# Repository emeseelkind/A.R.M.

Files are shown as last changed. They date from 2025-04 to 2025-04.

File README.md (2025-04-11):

# A.R.M. - Above-Elbow 3D-Printed Low-Cost Prosthetic

**Customizable Above-Elbow 3D-Printed Low-Cost Prosthetics**

By Queen's Biomedical Innovation Team (QBiT), the Perk Lab and Med-i Lab from Queen's University.

In collaboration with Burma Children Medical Fund (BCMF), a nonprofit based in Mae Sot, Tak, Thailand. BCMF focuses on funding medical treatment and support services, including accessible prosthetics for refugees and underserved Burmese communities along the Thai-Myanmar border. 

Our partnership focuses on designing and developing low-cost, 3D-printed, body-powered prosthetics. The labs provide both remote and on-site technical support and have sent three students to work in Mae Sot with BCMF so far.

This repository contains the CAD models and harness manual for our fully body-powered above-elbow prosthetic. The device is to be fabricated using locally available materials and support the everyday functional needs of patients.

# Features

• Fully body-powered design

• Made with materials accessible in-clinic

• Capable of assisting with common daily tasks

• Lightweight and easy to reproduce

• Total estimated material cost: $8.23–13.23 USD per device

• Open-source and adaptable for future development

# Files Included

• 5 CAD files for prosthetic components

• Harness system instructions and design notes

• Cost breakdown and materials list

• Preliminary testing results and feedback highlights

# In Progress

• Video demonstration of device assembly and usage will be added soon

• Ongoing testing with patients at BCMF in Thailand (April–August 2025)

• Planned integration into clinic workflow and future iterations for improved elbow movement and durability

• Movement of 5 fingers and interchangable end effectors will be added in the 2025-2026 school term

# Contact & Links

For inquiries or contributions:

• Email: qbit@engsoc.queensu.ca

• Website: [qbitqueensu.com](https://qbitqueensu.com)
           [labs.cs.queensu.ca/perklab/](https://labs.cs.queensu.ca/perklab/)
           [labs.cs.queensu.ca/medilab/](https://labs.cs.queensu.ca/medilab/)

**To volunteer, donate, or learn more please visit: [burmachildren.com/](https://burmachildren.com/)**

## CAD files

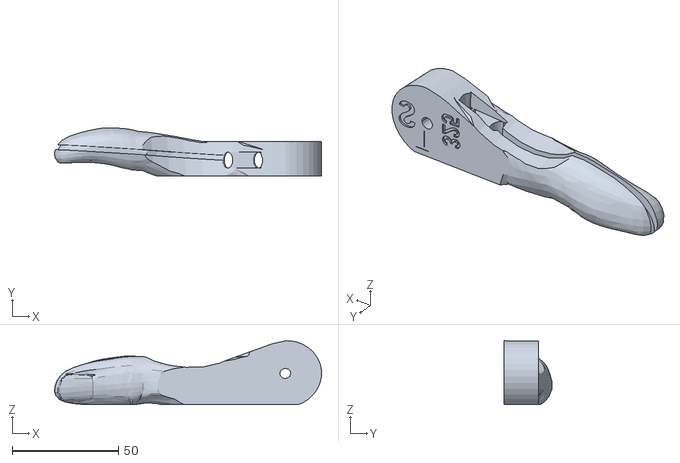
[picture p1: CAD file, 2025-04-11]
BCMFThumb.stl
125.7 x 22.8 x 30.2

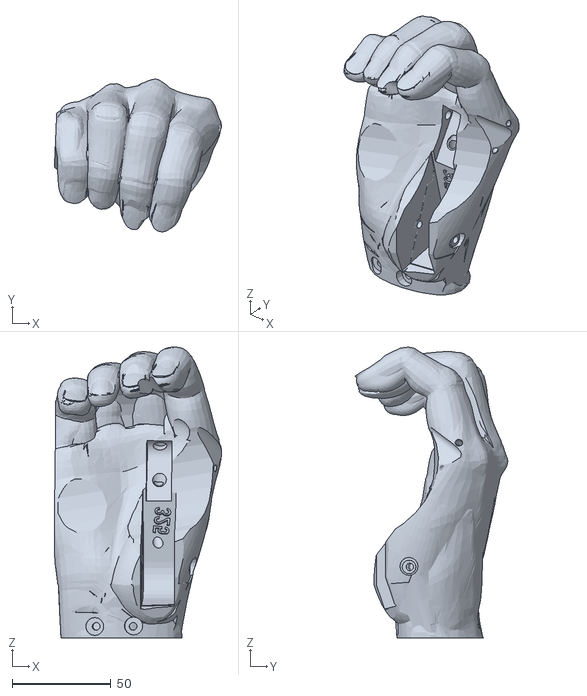
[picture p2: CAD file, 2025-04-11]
BCMFGripperHand.stl
84.9 x 77.6 x 147.7

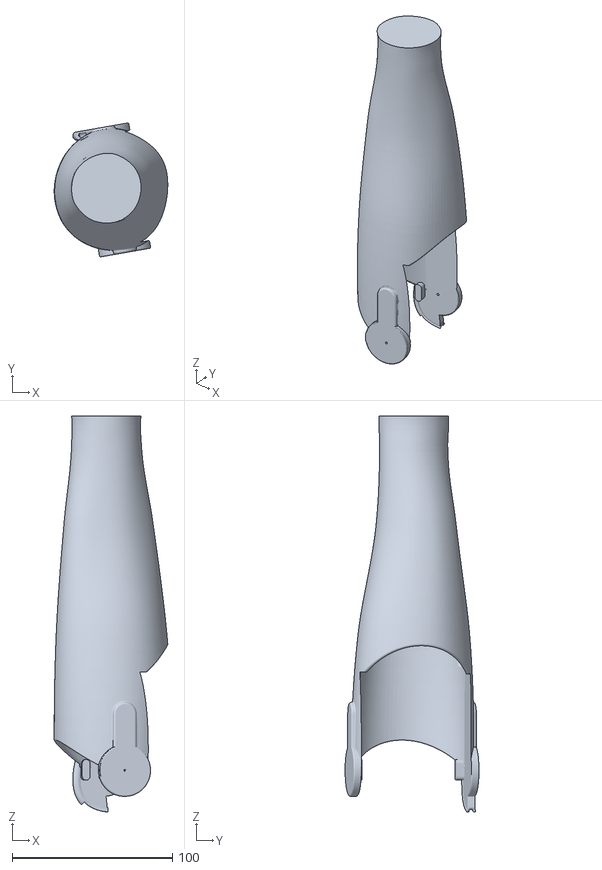
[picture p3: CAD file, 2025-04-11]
BCMFForearm.stl
70.8 x 83.6 x 246.9

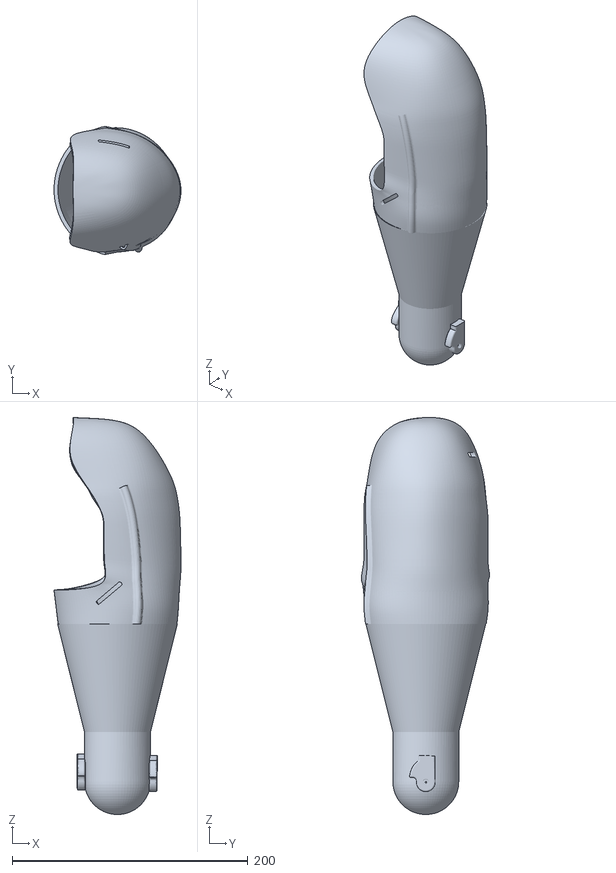
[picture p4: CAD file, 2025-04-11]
BCMFShoulder.stl
107.8 x 108.7 x 337.1

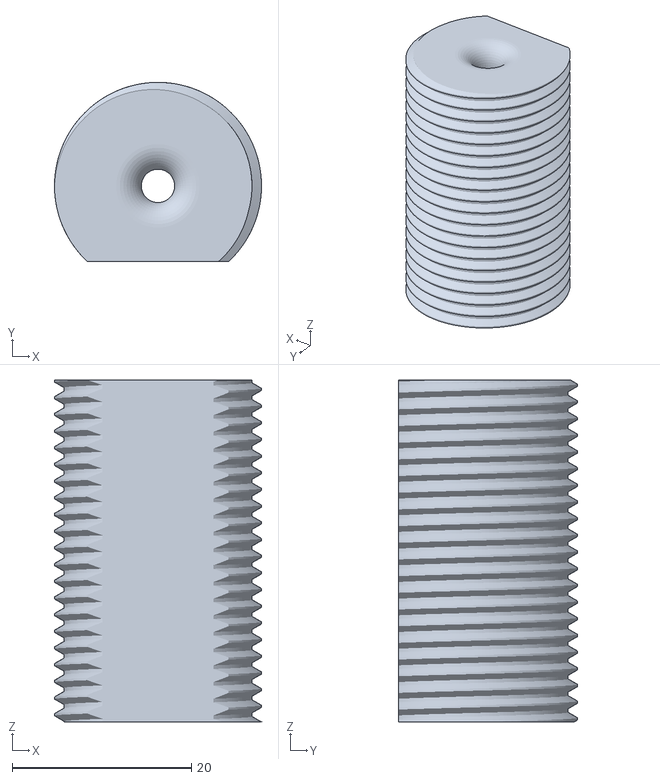
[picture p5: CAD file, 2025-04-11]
BCMFWristBolt.stl
23.1 x 20.0 x 38.1

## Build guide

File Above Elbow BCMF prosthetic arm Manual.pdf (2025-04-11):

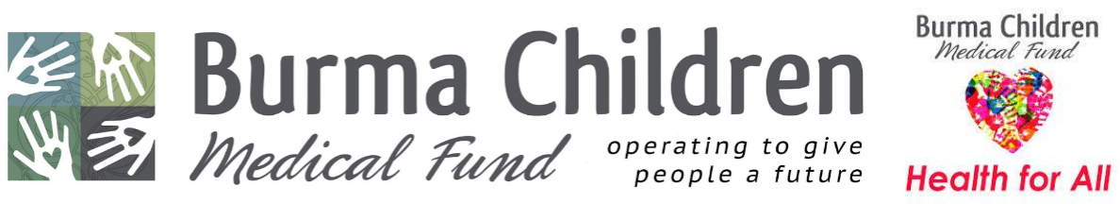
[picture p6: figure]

# Above-Elbow BCMF prosthetic arm Manual

By Queens Biomedical Innovation Team, the Perk Lab and the Med-I Lab.

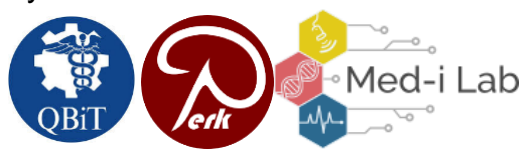
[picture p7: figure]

## Pieces to 3D print

1. Gripper Hand and thumb
2. Wrist bolt
3. Kwawu 2.0 modified forearm
4. Shoulder

## How to Assembling the Harness

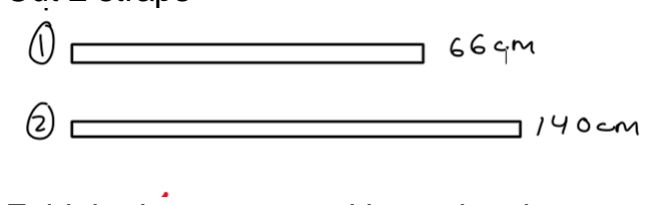
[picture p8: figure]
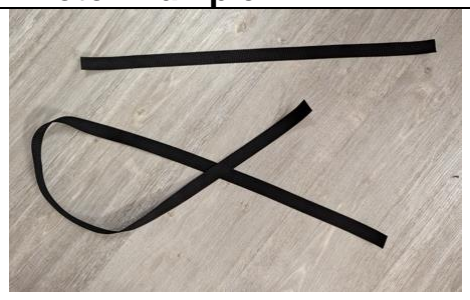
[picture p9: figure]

Instruction | Drawing | Photo Example
- Cut two black straps - One strap should be 66 cm, and the second strap should be 140 cm - Lay strap 1 (66cm) flat on the ground - Take the second strap (140 cm) and make a loop by crossing it over itself | Cut 2 straps Fold the long strap and keep the short strap straight

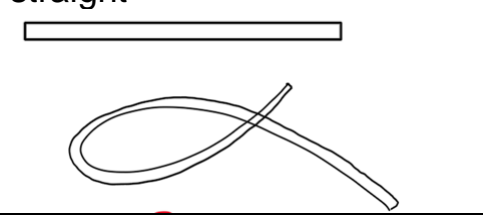
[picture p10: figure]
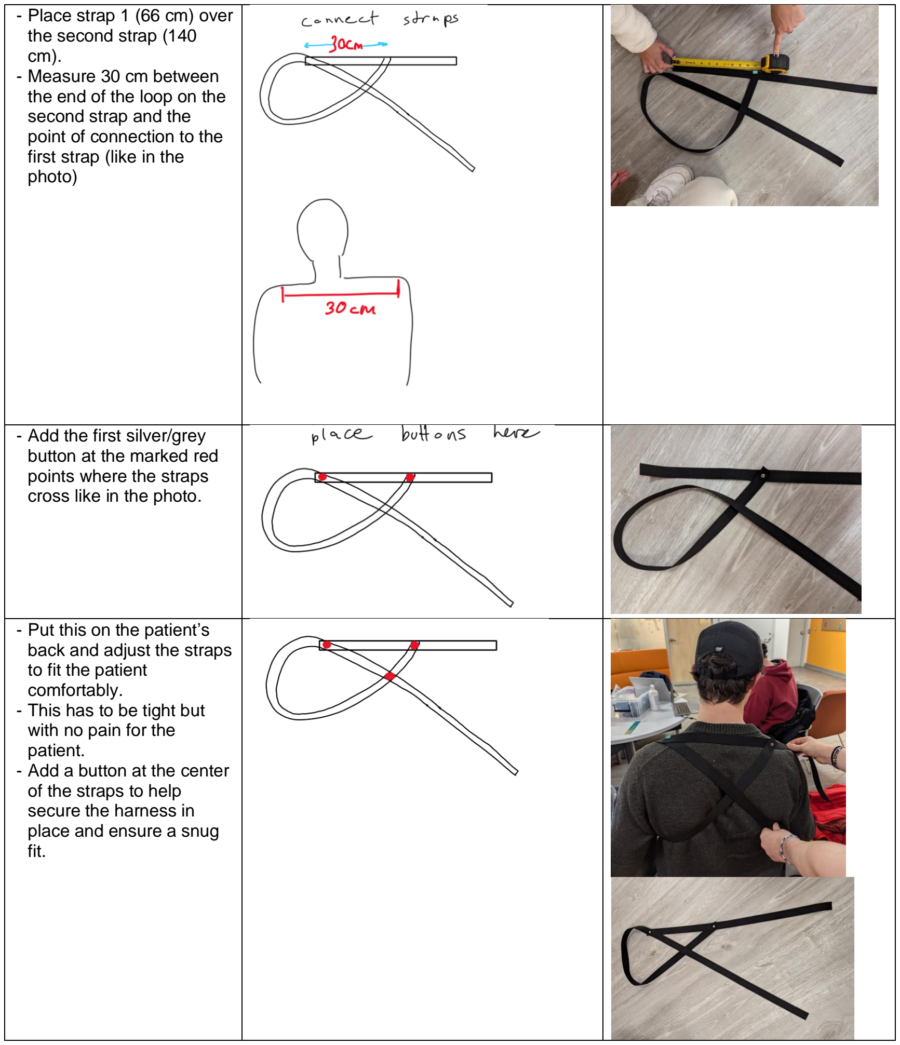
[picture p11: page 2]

- Place strap 1 (66 cm) over the second strap (140
cm).
- Measure 30 cm between
the end of the loop on the second strap and the
point of connection to the first strap (like in the
photo)
- Add the first silver/grey button at the marked red
points where the straps
cross like in the photo.
- Put this on the patient’s back and adjust the straps to fit the patient
comfortably.
- This has to be tight but with no pain for the
patient.
- Add a button at the center of the straps to help
secure the harness in
place and ensure a snug
fit.

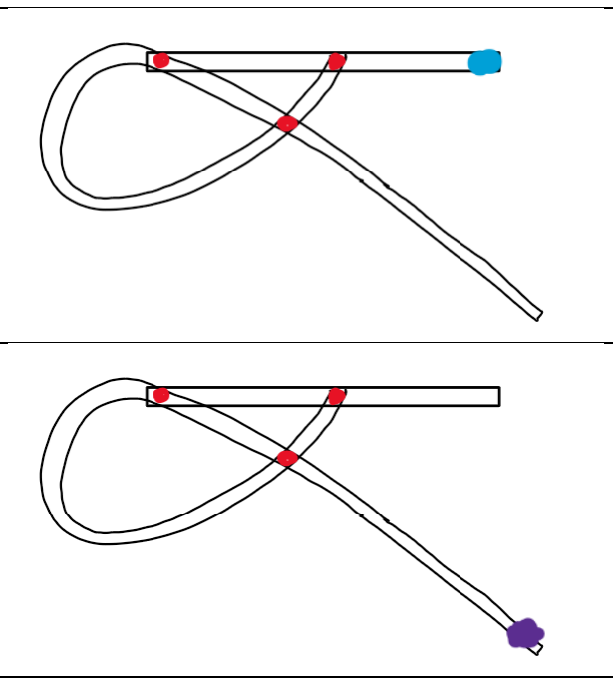
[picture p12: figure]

- Attach this blue section onto the shoulder with a silver button - There are 2 holes in the shoulder, please put it on the front one
- Drill a hole in the forearm to attach the purple section to it with a button - Test this with a patient to see where it is the best to drill a hole to move the arm.
